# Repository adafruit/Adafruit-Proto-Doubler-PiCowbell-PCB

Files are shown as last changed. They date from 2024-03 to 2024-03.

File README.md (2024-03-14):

## Adafruit Proto Doubler PiCowbell for Pico and PicoW PCB

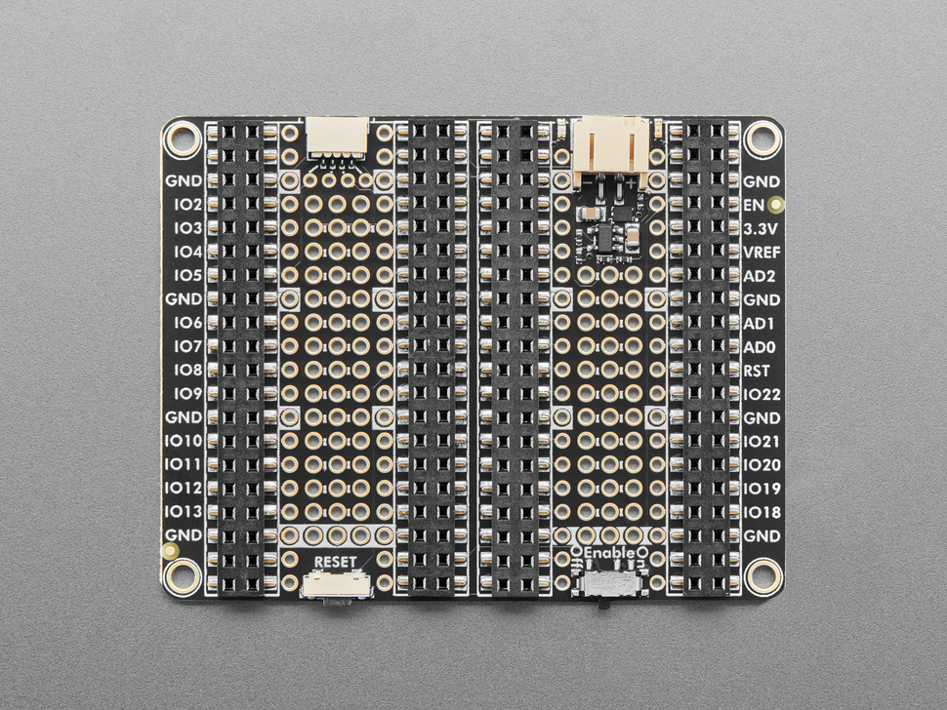
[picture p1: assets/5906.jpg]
<a href="http://www.adafruit.com/products/5906"><br/>
Click here to purchase one from the Adafruit shop</a>

PCB files for the Adafruit Proto Doubler PiCowbell for Pico and PicoW. 

Format is EagleCAD schematic and board layout
* https://www.adafruit.com/product/5906

### Description

The Adafruit Proto Doubler PiCowBell is intended to be treated like a mini solder-less proto plate to simplify programming and sensor connectivity for your Raspberry Pi Pico board. Reset button? Yes! STEMMA QT / Qwiic connector for fast I2C? Indeed. Battery with recharging and on/off switch? Affirmative. Plug-and-play so no soldering necessary when used with a Pico H or Pico WH? Here you go!

The Doubler is like if we used a 'Clone Tool' on the Proto Under Plate PiCowbell - you get two slots side-by-side which means you can easily add accessories to your Pico or Pico W without soldering on any stacking headers.

### LiPoly Battery Charging Support
The Doubler also gives you Lipoly/LiIon support circuitry so you can take your Pico project on the go. Use any 3.7V/4.2V single-cell Lithium battery with a JST 2-PH connector in the correct polarity. The battery will automagically charge with the Pico is plugged into USB, and switch over seamlessly to battery when USB power is removed.

By default the charge rate is 500mA for use with 500mAh+ sized batteries. You can cut a jumper to reduce the charge rate to 250mA if using 250mAh to 500mAh battery. So you don't have to unplug the battery often, a slide switch is connected to the Pico Enable pin, so you can disable the Pico's 3.3V power supply completely - this is as close as we can get to 'turning off' the Pico.

### Alkaline/NiMH Battery Pack Support
You can also cut a different jumper to disconnect the charger completely from the battery, which means you can use 3xAA or 3xAAA battery packs for alkaline or NiMH battery usage. Of course, you will need an external NiMH charger in that case. 

### Double Socket Headers
This board has double sockets already soldered on, you can plug in your Pico and 'Bell boards directly in, and get access to a prototyping area underneath as well as a second row of socket pins. The second row means you can connect wires just by poking them into the header, either directly to LEDs or buttons or to jumper to a breadboard. So you don't have to look up or count pins, each socket is nicely labeled. There's also 4 mounting holes for easy attachment to an underplate. 

The dual socket headers we use are 'hollow' - that means you can connect through the back if desired. Specifically, you can use Pico Stacking Headers to plug through to some other device that is expecting Pico pins. Also, in theory, if you soldered pin headers on the 'wrong side' of a Pico, you could plug it up through the bottom.

We recommend picking up a set of little rubber feet to protect your desk if you're not mounting this board to something else.

### Features:
* Two 2x20 slim socket headers - plug in your Pico and desired 'Bell and have an extra row of sockets for each pin!
* JST PH connector for LiIon/LiPoly or Alkaline/NiMH battery usage - be sure to cut the "disable charge" jumper to use Alkaline/NiMH batteries.
* LiPoly/LiIon charging circuitry for any 3.7V/4.2V nominal 1-cell battery. Default rate is 500mA, can be set to 250mA by cutting the charge-rate jumper on bottom. Two indicator LEDs let you know if battery is charging (orange) or complete (green)
* Slide switch connected to the Pico Enable pin, which will disable the 3.3V power supply.
* Reset button that sticks out the end
* JST SH connector for I2C / Stemma QT / Qwiic connection. Or can use it for plain GPIO wiring if you don't have any I2C devices to attach. Provides 3V, GND, IO4 (SDA), and IO5 (SCL)
* There is an extra set of 4 breakout holes next to the JST SH if you want more I2C connections or want to re-assign the I2C port.
* 3 hole-connected strips are in the center areas. You can cut the traces between the holes, but they're intended to be treated like a mini-mini breadboard
* Nearly-every pad on the Pico has a duplicate hole pad next to it for solder-jumpering
* The ground pads have white silkscreen rectangles to easily identify, plus one long ground strip near the reset button
* One long strip of connected holes for 3.3V power
* Gold-plated pads for easy soldering

We do not have I2C pullups on the board, but your Qwiic/QT breakout board or accessory likely already has them onboard. If using the Philhower Arduino core, the Wire peripheral is already set up to use IO4 and IO5. If using CircuitPython or MicroPython, you'll need to let the code know to look at 4+5 for SDA+SCL pins.

### License

Adafruit invests time and resources providing this open source design, please support Adafruit and open-source hardware by purchasing products from [Adafruit](https://www.adafruit.com)!

Designed by Limor Fried/Ladyada for Adafruit Industries.

Creative Commons Attribution/Share-Alike, all text above must be included in any redistribution. 
See license.txt for additional details.

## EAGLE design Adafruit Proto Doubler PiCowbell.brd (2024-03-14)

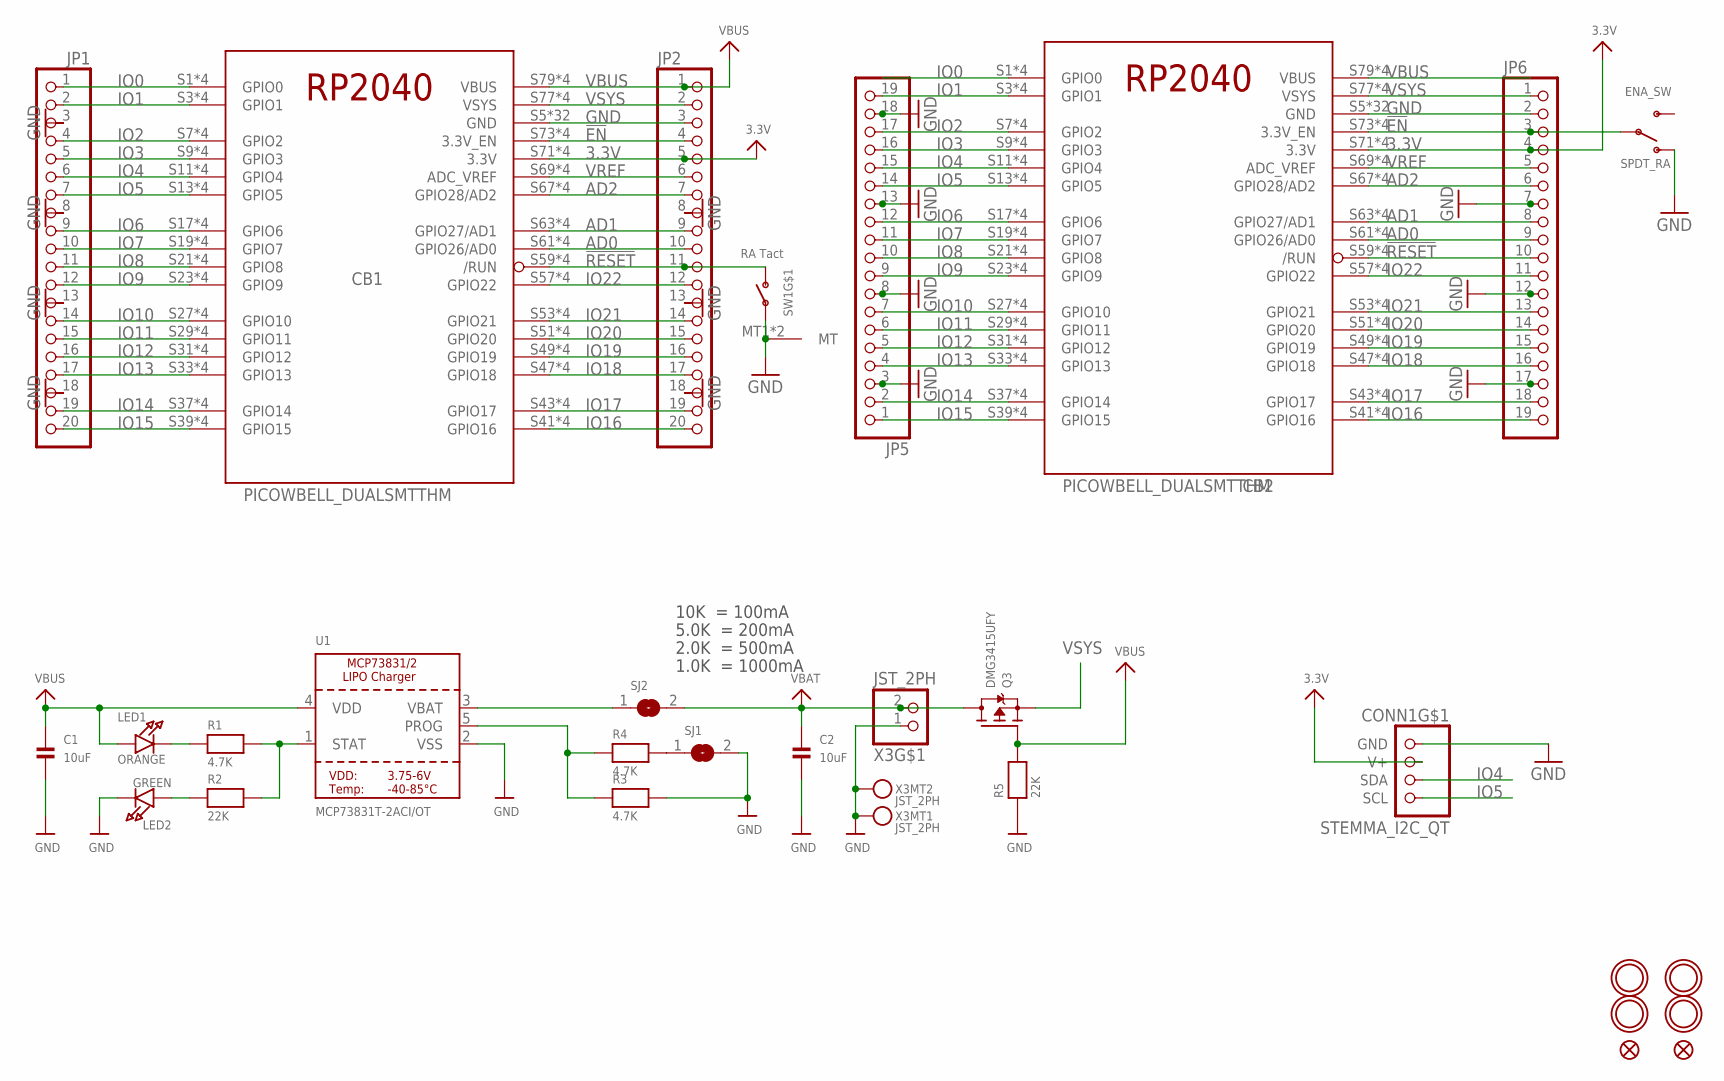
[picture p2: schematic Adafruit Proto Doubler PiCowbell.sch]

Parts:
C1, C2: 10uF; 0805-NO
CB1, CB2: PICOWBELL_DUALSMTTHM
CONN1: STEMMA_I2C_QT; JST_SH4
ENA_SW: SPDT_RA; SPDT_SMT_SSSS811101
FID1, FID2: FIDUCIAL_1MM
JP1, JP2: HEADER-1X20_70MIL; 1X20_ROUND_70MIL
JP5, JP6: HEADER-1X19; 1X19_ROUND
LED1: ORANGE; CHIPLED_0603_NOOUTLINE
LED2: GREEN; CHIPLED_0603_NOOUTLINE
Q3: DMG3415UFY; DFN2015-3
R1, R3, R4: 4.7K; _0402NO
R2, R5: 22K; _0402NO
SJ1, SJ2: SOLDERJUMPERCLOSED; SOLDERJUMPER_CLOSEDWIRE
SW1: RA Tact; SPST_TACTILE_RA
U1: MCP73831T-2ACI/OT; SOT23-5; JLC_ROTATION 0
U$5, U$7, U$15, U$16: MOUNTINGHOLE2.5; MOUNTINGHOLE_2.5_PLATED
X3: JST_2PH; JSTPH2_BATT

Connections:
3.3V: CB1.S71 (3.3V), CB1.S72 (3.3V), CB1.T71 (3.3V), CB1.T72 (3.3V), CB2.S71 (3.3V), CB2.S72 (3.3V), CB2.T71 (3.3V), CB2.T72 (3.3V), CONN1.2 (V+), JP2.5, JP6.4
!EN: CB1.S73 (3.3V_EN), CB1.S74 (3.3V_EN), CB1.T73 (3.3V_EN), CB1.T74 (3.3V_EN), CB2.S73 (3.3V_EN), CB2.S74 (3.3V_EN), CB2.T73 (3.3V_EN), CB2.T74 (3.3V_EN), ENA_SW.B, JP2.4, JP6.3
!RESET: CB1.S59 (/RUN), CB1.S60 (/RUN), CB1.T59 (/RUN), CB1.T60 (/RUN), CB2.S59 (/RUN), CB2.S60 (/RUN), CB2.T59 (/RUN), CB2.T60 (/RUN), JP2.11, JP6.10, SW1.2 (S)
AD0: CB1.S61 (GPIO26/AD0), CB1.S62 (GPIO26/AD0), CB1.T61 (GPIO26/AD0), CB1.T62 (GPIO26/AD0), CB2.S61 (GPIO26/AD0), CB2.S62 (GPIO26/AD0), CB2.T61 (GPIO26/AD0), CB2.T62 (GPIO26/AD0), JP2.10, JP6.9
AD1: CB1.S63 (GPIO27/AD1), CB1.S64 (GPIO27/AD1), CB1.T63 (GPIO27/AD1), CB1.T64 (GPIO27/AD1), CB2.S63 (GPIO27/AD1), CB2.S64 (GPIO27/AD1), CB2.T63 (GPIO27/AD1), CB2.T64 (GPIO27/AD1), JP2.9, JP6.8
AD2: CB1.S67 (GPIO28/AD2), CB1.S68 (GPIO28/AD2), CB1.T67 (GPIO28/AD2), CB1.T68 (GPIO28/AD2), CB2.S67 (GPIO28/AD2), CB2.S68 (GPIO28/AD2), CB2.T67 (GPIO28/AD2), CB2.T68 (GPIO28/AD2), JP2.7, JP6.6
GND: C1.2, C2.2, CB1.S5 (GND), CB1.S6 (GND), CB1.S15 (GND), CB1.S16 (GND), CB1.S25 (GND), CB1.S26 (GND), CB1.S35 (GND), CB1.S36 (GND), CB1.S45 (GND), CB1.S46 (GND), CB1.S55 (GND), CB1.S56 (GND), CB1.S65 (GND), CB1.S66 (GND), CB1.S75 (GND), CB1.S76 (GND), CB1.T5 (GND), CB1.T6 (GND), CB1.T15 (GND), CB1.T16 (GND), CB1.T25 (GND), CB1.T26 (GND), CB1.T35 (GND), CB1.T36 (GND), CB1.T45 (GND), CB1.T46 (GND), CB1.T55 (GND), CB1.T56 (GND), CB1.T65 (GND), CB1.T66 (GND), CB1.T75 (GND), CB1.T76 (GND), CB2.S5 (GND), CB2.S6 (GND), CB2.S15 (GND), CB2.S16 (GND), CB2.S25 (GND), CB2.S26 (GND), CB2.S35 (GND), CB2.S36 (GND), CB2.S45 (GND), CB2.S46 (GND), CB2.S55 (GND), CB2.S56 (GND), CB2.S65 (GND), CB2.S66 (GND), CB2.S75 (GND), CB2.S76 (GND), CB2.T5 (GND), CB2.T6 (GND), CB2.T15 (GND), CB2.T16 (GND), CB2.T25 (GND), CB2.T26 (GND), CB2.T35 (GND), CB2.T36 (GND), CB2.T45 (GND), CB2.T46 (GND), CB2.T55 (GND), CB2.T56 (GND), CB2.T65 (GND), CB2.T66 (GND), CB2.T75 (GND), CB2.T76 (GND), CONN1.1 (GND), ENA_SW.A (O), JP1.3, JP1.8, JP1.13, JP1.18, JP2.3, JP2.8, JP2.13, JP2.18, JP5.3, JP5.8, JP5.13, JP5.18, JP6.2, JP6.7, JP6.12, JP6.17, LED2.C, R3.2, R5.1, SJ1.2, SW1.1, SW1.MT1 (MT), SW1.MT2 (MT), U1.2 (VSS), X3.1, X3.NC1, X3.NC2
IO0: CB1.S1 (GPIO0), CB1.S2 (GPIO0), CB1.T1 (GPIO0), CB1.T2 (GPIO0), CB2.S1 (GPIO0), CB2.S2 (GPIO0), CB2.T1 (GPIO0), CB2.T2 (GPIO0), JP1.1
IO1: CB1.S3 (GPIO1), CB1.S4 (GPIO1), CB1.T3 (GPIO1), CB1.T4 (GPIO1), CB2.S3 (GPIO1), CB2.S4 (GPIO1), CB2.T3 (GPIO1), CB2.T4 (GPIO1), JP1.2, JP5.19
IO2: CB1.S7 (GPIO2), CB1.S8 (GPIO2), CB1.T7 (GPIO2), CB1.T8 (GPIO2), CB2.S7 (GPIO2), CB2.S8 (GPIO2), CB2.T7 (GPIO2), CB2.T8 (GPIO2), JP1.4, JP5.17
IO3: CB1.S9 (GPIO3), CB1.S10 (GPIO3), CB1.T9 (GPIO3), CB1.T10 (GPIO3), CB2.S9 (GPIO3), CB2.S10 (GPIO3), CB2.T9 (GPIO3), CB2.T10 (GPIO3), JP1.5, JP5.16
IO4: CB1.S11 (GPIO4), CB1.S12 (GPIO4), CB1.T11 (GPIO4), CB1.T12 (GPIO4), CB2.S11 (GPIO4), CB2.S12 (GPIO4), CB2.T11 (GPIO4), CB2.T12 (GPIO4), CONN1.3 (SDA), JP1.6, JP5.15
IO5: CB1.S13 (GPIO5), CB1.S14 (GPIO5), CB1.T13 (GPIO5), CB1.T14 (GPIO5), CB2.S13 (GPIO5), CB2.S14 (GPIO5), CB2.T13 (GPIO5), CB2.T14 (GPIO5), CONN1.4 (SCL), JP1.7, JP5.14
IO6: CB1.S17 (GPIO6), CB1.S18 (GPIO6), CB1.T17 (GPIO6), CB1.T18 (GPIO6), CB2.S17 (GPIO6), CB2.S18 (GPIO6), CB2.T17 (GPIO6), CB2.T18 (GPIO6), JP1.9, JP5.12
IO7: CB1.S19 (GPIO7), CB1.S20 (GPIO7), CB1.T19 (GPIO7), CB1.T20 (GPIO7), CB2.S19 (GPIO7), CB2.S20 (GPIO7), CB2.T19 (GPIO7), CB2.T20 (GPIO7), JP1.10, JP5.11
IO8: CB1.S21 (GPIO8), CB1.S22 (GPIO8), CB1.T21 (GPIO8), CB1.T22 (GPIO8), CB2.S21 (GPIO8), CB2.S22 (GPIO8), CB2.T21 (GPIO8), CB2.T22 (GPIO8), JP1.11, JP5.10
IO9: CB1.S23 (GPIO9), CB1.S24 (GPIO9), CB1.T23 (GPIO9), CB1.T24 (GPIO9), CB2.S23 (GPIO9), CB2.S24 (GPIO9), CB2.T23 (GPIO9), CB2.T24 (GPIO9), JP1.12, JP5.9
IO10: CB1.S27 (GPIO10), CB1.S28 (GPIO10), CB1.T27 (GPIO10), CB1.T28 (GPIO10), CB2.S27 (GPIO10), CB2.S28 (GPIO10), CB2.T27 (GPIO10), CB2.T28 (GPIO10), JP1.14, JP5.7
IO11: CB1.S29 (GPIO11), CB1.S30 (GPIO11), CB1.T29 (GPIO11), CB1.T30 (GPIO11), CB2.S29 (GPIO11), CB2.S30 (GPIO11), CB2.T29 (GPIO11), CB2.T30 (GPIO11), JP1.15, JP5.6
IO12: CB1.S31 (GPIO12), CB1.S32 (GPIO12), CB1.T31 (GPIO12), CB1.T32 (GPIO12), CB2.S31 (GPIO12), CB2.S32 (GPIO12), CB2.T31 (GPIO12), CB2.T32 (GPIO12), JP1.16, JP5.5
IO13: CB1.S33 (GPIO13), CB1.S34 (GPIO13), CB1.T33 (GPIO13), CB1.T34 (GPIO13), CB2.S33 (GPIO13), CB2.S34 (GPIO13), CB2.T33 (GPIO13), CB2.T34 (GPIO13), JP1.17, JP5.4
IO14: CB1.S37 (GPIO14), CB1.S38 (GPIO14), CB1.T37 (GPIO14), CB1.T38 (GPIO14), CB2.S37 (GPIO14), CB2.S38 (GPIO14), CB2.T37 (GPIO14), CB2.T38 (GPIO14), JP1.19, JP5.2
IO15: CB1.S39 (GPIO15), CB1.S40 (GPIO15), CB1.T39 (GPIO15), CB1.T40 (GPIO15), CB2.S39 (GPIO15), CB2.S40 (GPIO15), CB2.T39 (GPIO15), CB2.T40 (GPIO15), JP1.20, JP5.1
IO16: CB1.S41 (GPIO16), CB1.S42 (GPIO16), CB1.T41 (GPIO16), CB1.T42 (GPIO16), CB2.S41 (GPIO16), CB2.S42 (GPIO16), CB2.T41 (GPIO16), CB2.T42 (GPIO16), JP2.20, JP6.19
IO17: CB1.S43 (GPIO17), CB1.S44 (GPIO17), CB1.T43 (GPIO17), CB1.T44 (GPIO17), CB2.S43 (GPIO17), CB2.S44 (GPIO17), CB2.T43 (GPIO17), CB2.T44 (GPIO17), JP2.19, JP6.18
IO18: CB1.S47 (GPIO18), CB1.S48 (GPIO18), CB1.T47 (GPIO18), CB1.T48 (GPIO18), CB2.S47 (GPIO18), CB2.S48 (GPIO18), CB2.T47 (GPIO18), CB2.T48 (GPIO18), JP2.17, JP6.16
IO19: CB1.S49 (GPIO19), CB1.S50 (GPIO19), CB1.T49 (GPIO19), CB1.T50 (GPIO19), CB2.S49 (GPIO19), CB2.S50 (GPIO19), CB2.T49 (GPIO19), CB2.T50 (GPIO19), JP2.16, JP6.15
IO20: CB1.S51 (GPIO20), CB1.S52 (GPIO20), CB1.T51 (GPIO20), CB1.T52 (GPIO20), CB2.S51 (GPIO20), CB2.S52 (GPIO20), CB2.T51 (GPIO20), CB2.T52 (GPIO20), JP2.15, JP6.14
IO21: CB1.S53 (GPIO21), CB1.S54 (GPIO21), CB1.T53 (GPIO21), CB1.T54 (GPIO21), CB2.S53 (GPIO21), CB2.S54 (GPIO21), CB2.T53 (GPIO21), CB2.T54 (GPIO21), JP2.14, JP6.13
IO22: CB1.S57 (GPIO22), CB1.S58 (GPIO22), CB1.T57 (GPIO22), CB1.T58 (GPIO22), CB2.S57 (GPIO22), CB2.S58 (GPIO22), CB2.T57 (GPIO22), CB2.T58 (GPIO22), JP2.12, JP6.11
unnamed: R4.2, SJ1.1
unnamed: SJ2.1, U1.3 (VBAT)
unnamed: LED1.C, R1.1
unnamed: R1.2, R2.2, U1.1 (STAT)
unnamed: LED2.A, R2.1
unnamed: R3.1, R4.1, U1.5 (PROG)
VBAT: C2.1, Q3.3 (D), SJ2.2, X3.2
VBUS: C1.1, CB1.S79 (VBUS), CB1.S80 (VBUS), CB1.T79 (VBUS), CB1.T80 (VBUS), CB2.S79 (VBUS), CB2.S80 (VBUS), CB2.T79 (VBUS), CB2.T80 (VBUS), JP2.1, LED1.A, Q3.1 (G), R5.2, U1.4 (VDD)
VREF: CB1.S69 (ADC_VREF), CB1.S70 (ADC_VREF), CB1.T69 (ADC_VREF), CB1.T70 (ADC_VREF), CB2.S69 (ADC_VREF), CB2.S70 (ADC_VREF), CB2.T69 (ADC_VREF), CB2.T70 (ADC_VREF), JP2.6, JP6.5
VSYS: CB1.S77 (VSYS), CB1.S78 (VSYS), CB1.T77 (VSYS), CB1.T78 (VSYS), CB2.S77 (VSYS), CB2.S78 (VSYS), CB2.T77 (VSYS), CB2.T78 (VSYS), JP2.2, JP6.1, Q3.2 (S)

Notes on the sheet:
10K = 100mA
5.0K = 200mA
2.0K = 500mA
1.0K = 1000mA

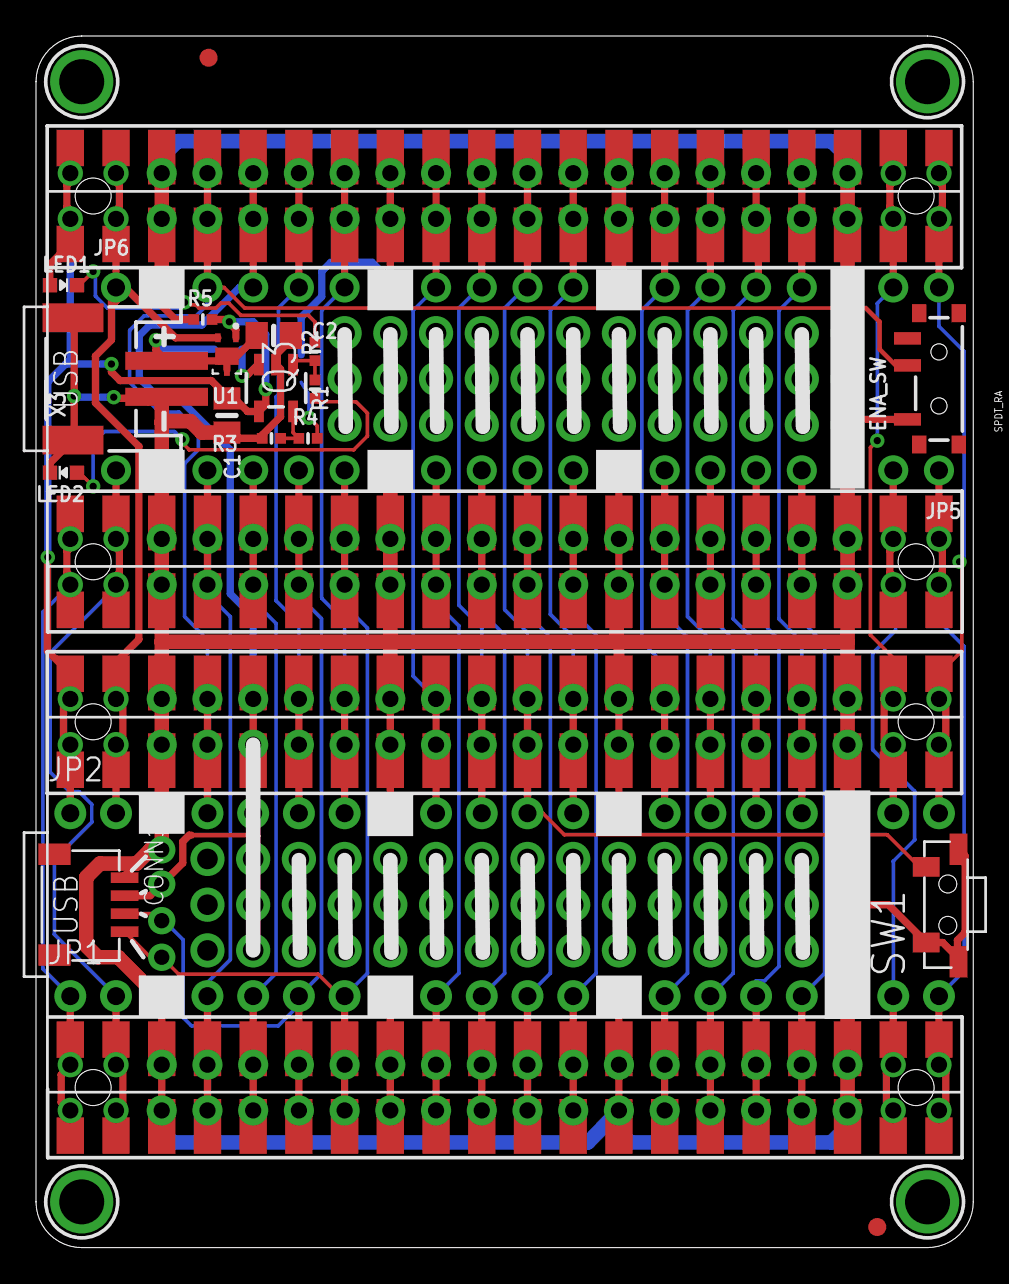
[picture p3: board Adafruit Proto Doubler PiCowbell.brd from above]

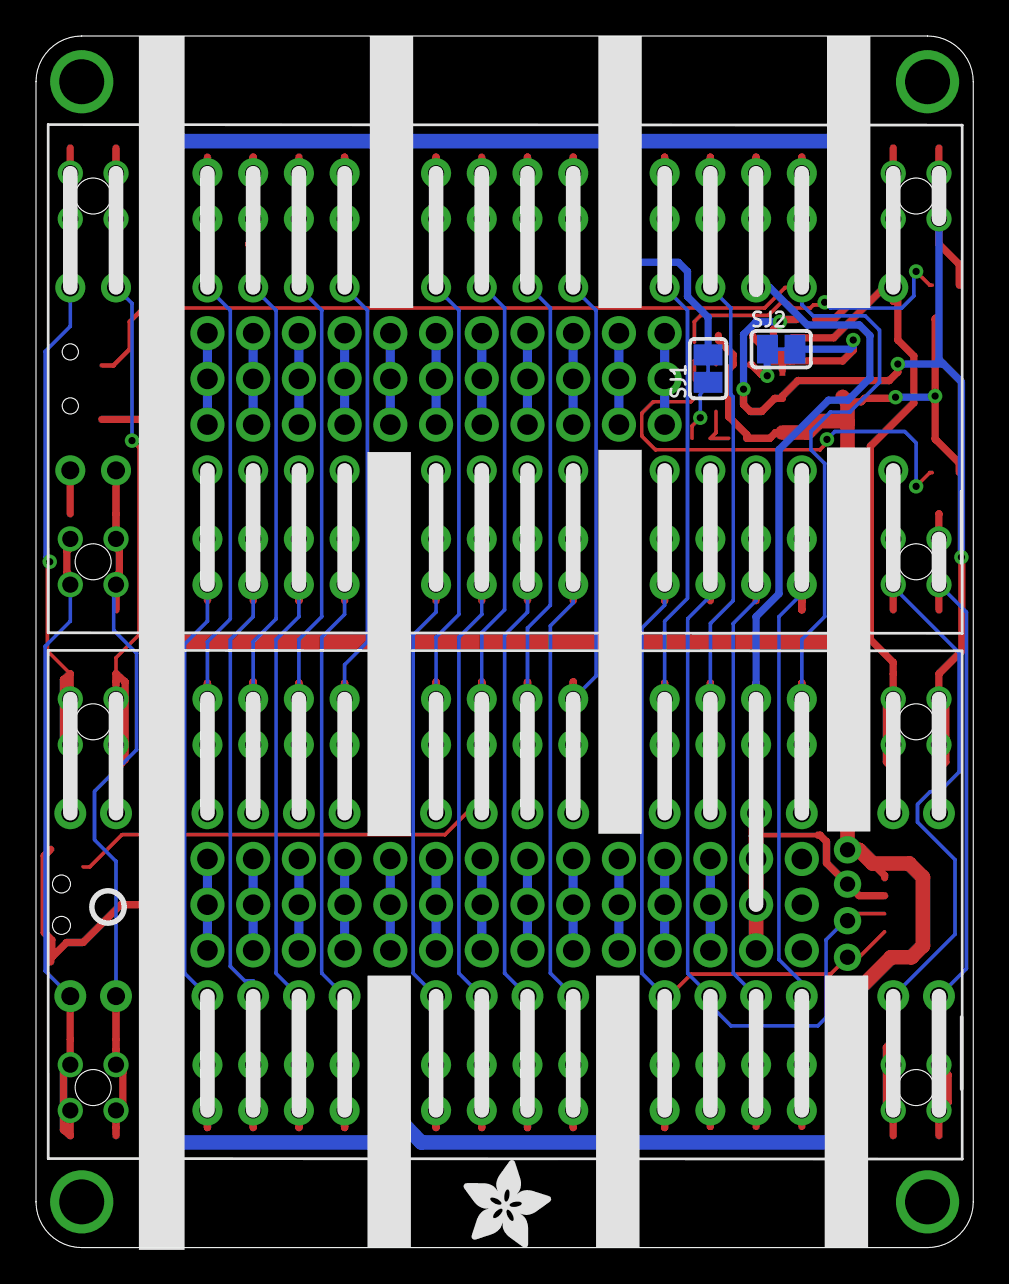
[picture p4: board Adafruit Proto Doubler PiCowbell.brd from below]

Board: 2 copper layers, 52.1 x 67.3 mm, 80 parts (17 on the bottom side), 40 nets.

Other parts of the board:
PLABEL0: PLABEL0
PLABEL1: PLABEL1
PLABEL2: PLABEL2
PLABEL3: PLABEL3
PLABEL4: PLABEL4
PLABEL5: PLABEL5
PLABEL6: PLABEL6
PLABEL7: PLABEL7
PLABEL8: PLABEL8
PLABEL9: PLABEL9
PLABEL10: PLABEL10
PLABEL11: PLABEL11
PLABEL12: PLABEL12
PLABEL13: PLABEL13
PLABEL14: PLABEL14
PLABEL15: PLABEL15
PLABEL16: PLABEL16
PLABEL36: PLABEL36
PLABEL37: PLABEL37
PLABEL38: PLABEL38
PLABEL39: PLABEL39
PLABEL40: PLABEL40
PLABEL41: PLABEL41
PLABEL42: PLABEL42
PLABEL43: PLABEL43
PLABEL44: PLABEL44
PLABEL45: PLABEL45
PLABEL46: PLABEL46
PLABEL47: PLABEL47
PLABEL48: PLABEL48
PLABEL59: PLABEL17
PLABEL60: PLABEL18
PLABEL61: PLABEL19
PLABEL62: PLABEL20
PLABEL63: PLABEL21
PLABEL64: PLABEL22
PLABEL65: PLABEL23
PLABEL66: PLABEL24
PLABEL67: PLABEL25
PLABEL68: PLABEL26
PLABEL69: PLABEL27
PLABEL70: PLABEL28
PLABEL71: PLABEL29
PLABEL72: PLABEL30
PLABEL73: PLABEL31
PLABEL74: PLABEL32
PLABEL75: PLABEL33
PLABEL76: PLABEL34
PLABEL77: PLABEL35
U$6: PCBFEAT-REV-040
U$10: ADAFRUIT_5MM

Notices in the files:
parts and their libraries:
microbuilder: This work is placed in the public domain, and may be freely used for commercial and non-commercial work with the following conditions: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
